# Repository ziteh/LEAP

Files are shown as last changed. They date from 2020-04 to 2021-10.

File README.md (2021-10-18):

:warning: This repo is no longer updated, I will continue to develop LEAP in [ziteh/LEAP-upper-limb](https://github.com/ziteh/LEAP-upper-limb).

---  

"**Lightweight Exoskeleton with Assistive Power (LEAP**)" is my independent study.

「**輔助性動力輕型外骨骼 (LEAP, 飛躍)**」是我的獨立研究。

# 影片展示

第二次步行測試 (https://www.youtube.com/watch?v=bzW2kFukcrA)

# 說明

## MCU

我使用的微控制器型號為 STM32F103RB，是基於 ARM Cortex M3 的 32 位元微控制器。

本專案使用的 IDE 爲[ Atollic TrueSTUDIO](https://atollic.com/truestudio/)，這是 ST 官方維護、由開源的[ Eclipse ](https://www.eclipse.org/downloads/)發展而來的 IDE。

目前本專案可正常運作的專案在[ LEAP/stm32/LAEPK_STM32_Cpp ](https://github.com/ziteh/LEAP/tree/master/stm32/LAEPK_STM32_Cpp)，可以使用 TrueSTUDIO 直接開啓專案。

## 電腦端程式

電腦端程式可以查看外骨骼的相關數值與狀態，也可以控制其動作等。

# 相關檔案

* STM32 微控制器程式： [LEAP/stm32/](https://github.com/ziteh/LEAP/tree/master/stm32/)
* 電腦端程式：[LEAP/PC_control_panel/](https://github.com/ziteh/LEAP/tree/master/PC_control_panel)
* 手機端程式：[LEAP-android-control-panel](https://github.com/ziteh/LEAP-android-control-panel)
* 3D 模型：[LEAP/3D_models/](https://github.com/ziteh/LEAP/tree/master/3D_models)
* PCB 電路：[LEAP/pcb/](https://github.com/ziteh/LEAP/tree/master/pcb)

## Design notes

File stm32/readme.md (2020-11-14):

# L.E.A.P stm32

這是 L.E.A.P 的 STM32 微控制器程式部分，使用 C/C++ 編寫，IDE 爲 TrueSTUDIO。

當前版本在[LAEPK_STM32_Cpp](LAEPK_STM32_Cpp)

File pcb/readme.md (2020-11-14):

# L.E.A.P pcb

這是 L.E.A.P 的 PCB 電路部分，使用 KiCad。

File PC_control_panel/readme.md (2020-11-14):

# L.E.A.P PC_control_panel

這是 L.E.A.P 的電腦端程式部分，使用 Visual Studio C# 編寫而成。

當前版本在[LEAP-ControlPanel](LEAP-ControlPanel)

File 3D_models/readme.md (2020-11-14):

# L.E.A.P 3D_models

這是 L.E.A.P 的 3D 模型部分。

當前版本在[Solidworks](Solidworks)

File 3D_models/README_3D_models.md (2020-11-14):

# L.E.A.P 3D_models

這是 L.E.A.P 的 3D 模型部分。

當前版本在[Solidworks](/Solidworks)

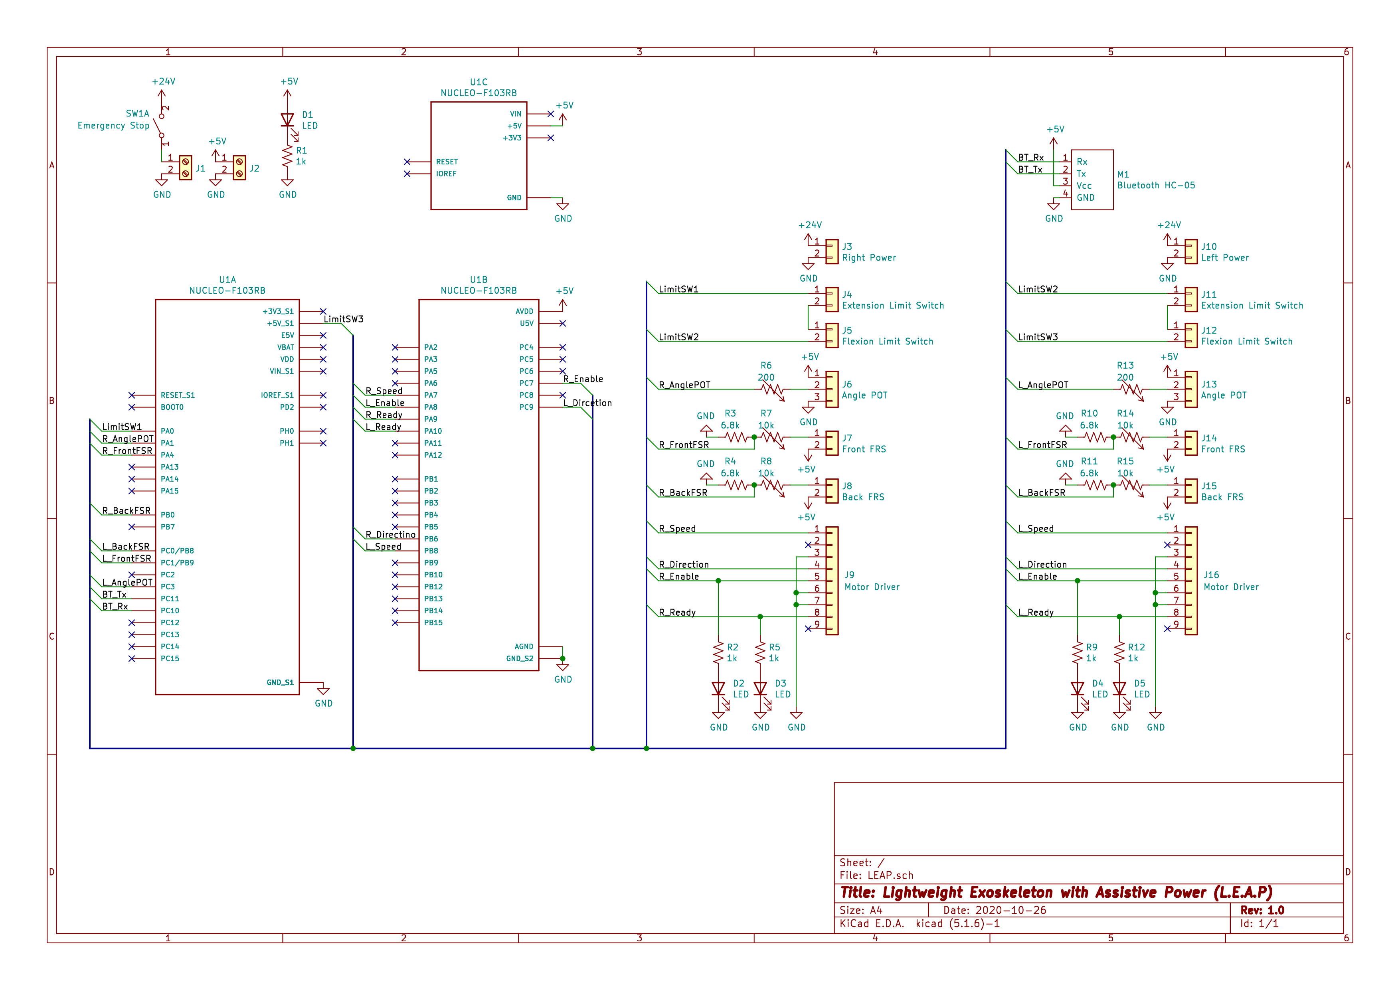
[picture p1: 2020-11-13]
pcb/LEAPsch-01.png

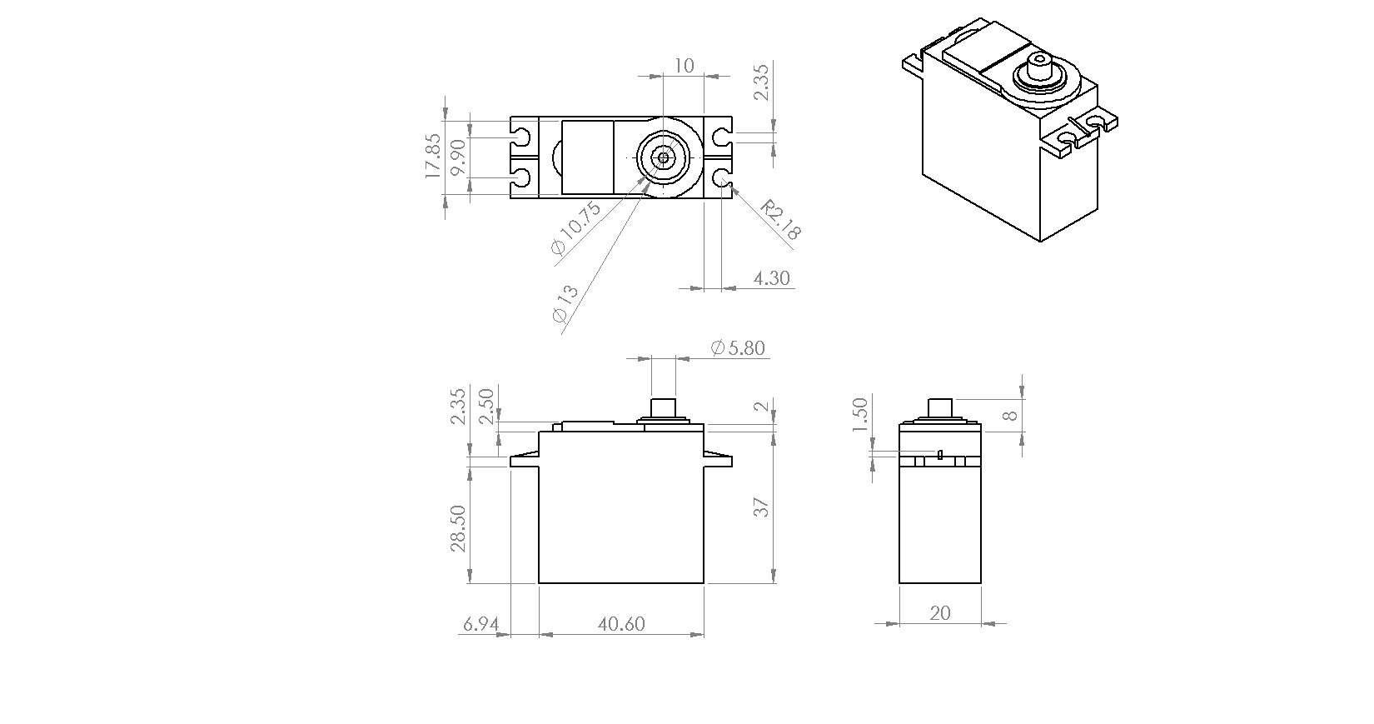
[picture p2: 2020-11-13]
3D_models/Solidworks/縮小測試用模型v2/MG996R[01-v1.PNG

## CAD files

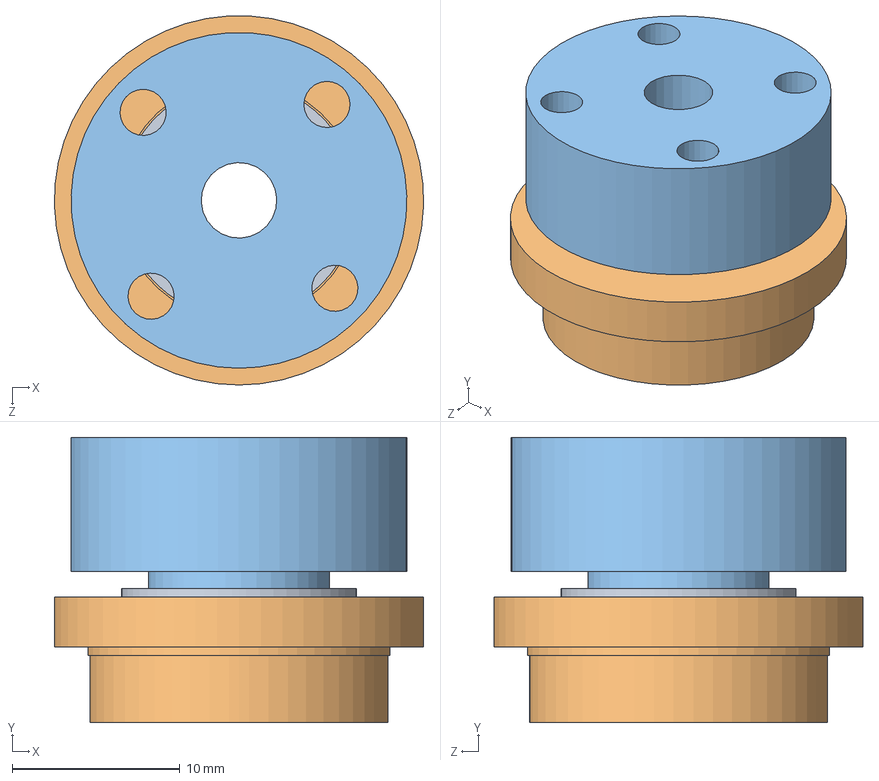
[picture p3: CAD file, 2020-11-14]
3D_models/Solidworks/下肢/組合/HD軸向固定組合[01_v2.0].SLDASM
22.0 x 17.0 x 22.0 mm
軸承_HD軸向固定(01-v1.0)
HD軸向軸承固定塊(01_v1.0)
HD軸向軸承固定塊(02_v2.0)

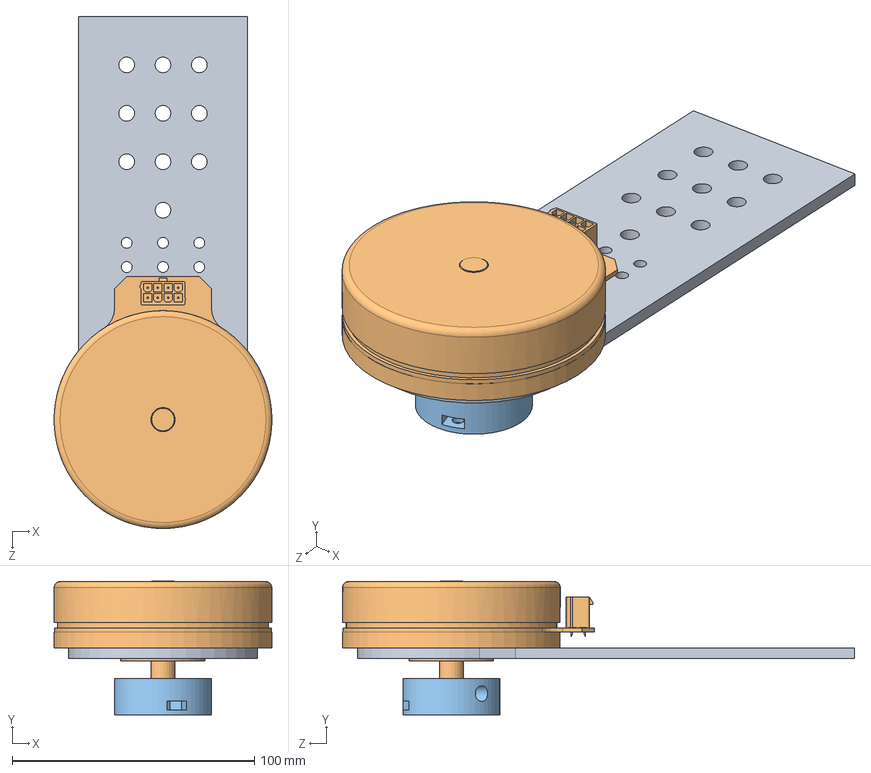
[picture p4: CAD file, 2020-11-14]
3D_models/Solidworks/下肢/組合/EC90flat固定片塊組合[01_v1.0].SLDASM
90.0 x 55.3 x 211.5 mm
EC90flot固定片(01_v3.1)
EC90fl-160W-586655
EC90flot軸心固定塊(01_v3.1)

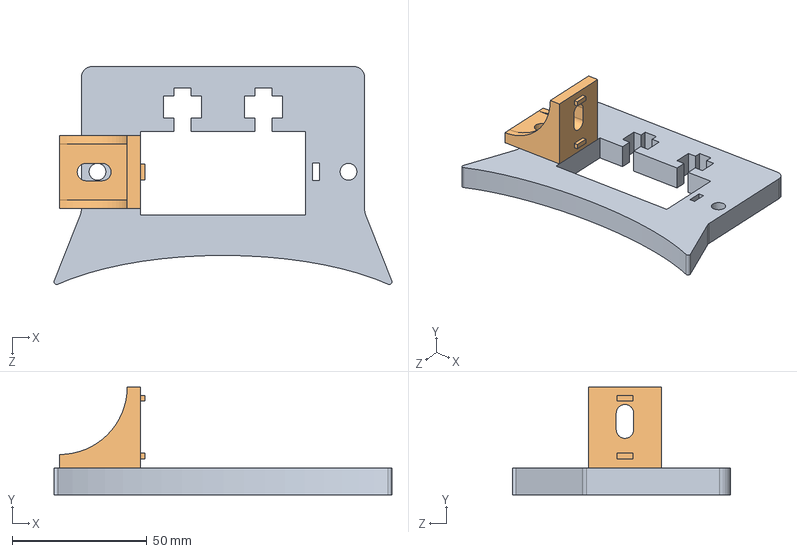
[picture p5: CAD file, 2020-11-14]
3D_models/Solidworks/下肢/組合/大腿固定片組合[01_v1.0].SLDASM
125.2 x 40.0 x 80.8 mm
大腿固定片[01_v1.0]
3030鋁擠型三角件M6[01-v1.0]

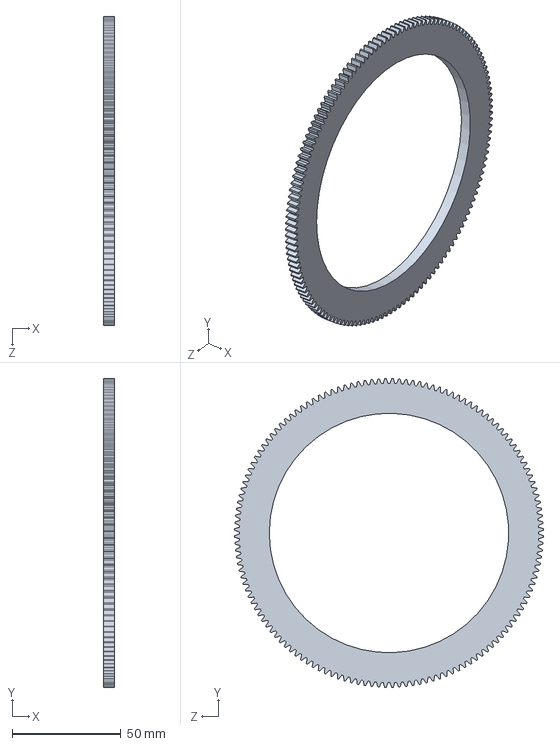
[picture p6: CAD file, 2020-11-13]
3D_models/Solidworks/下肢/Others/編碼器用大齒輪[01_v1.0].SLDASM
5.00 x 142.0 x 142.0 mm

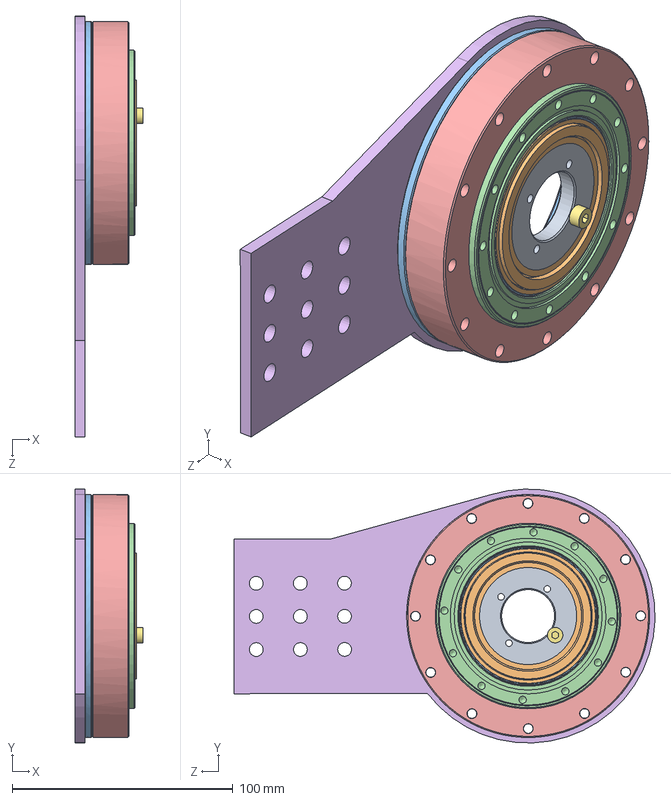
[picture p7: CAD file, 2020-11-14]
3D_models/Solidworks/下肢/組合/SHD-25-2SH固定片組合[01_v1.0].SLDASM
30.9 x 114.9 x 190.6 mm
SHD-25-2SH-WG
25 WG BEARING DS
SHD-25-2SH-FS
SHD-25-2SH-CS
SHD-25-2SH-FS2
SHD-2SH_彈性齒杯固定片(01_v4.2)

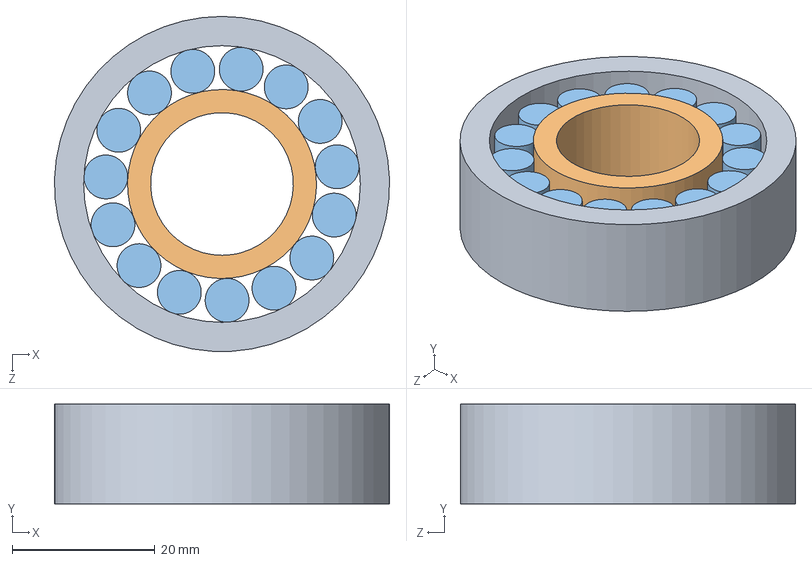
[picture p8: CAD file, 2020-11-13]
3D_models/Solidworks/下肢/機械/軸承(SKF單列圓柱滾子20)_組合-01_v1.0.SLDASM
47.0 x 14.0 x 47.0 mm
軸承(SKF單列圓柱滾子20)_外圈-01_v1.0
軸承(SKF單列圓柱滾子20)_内圈-01_v1.0
軸承(SKF單列圓柱滾子20)_滾子-01_v1.0

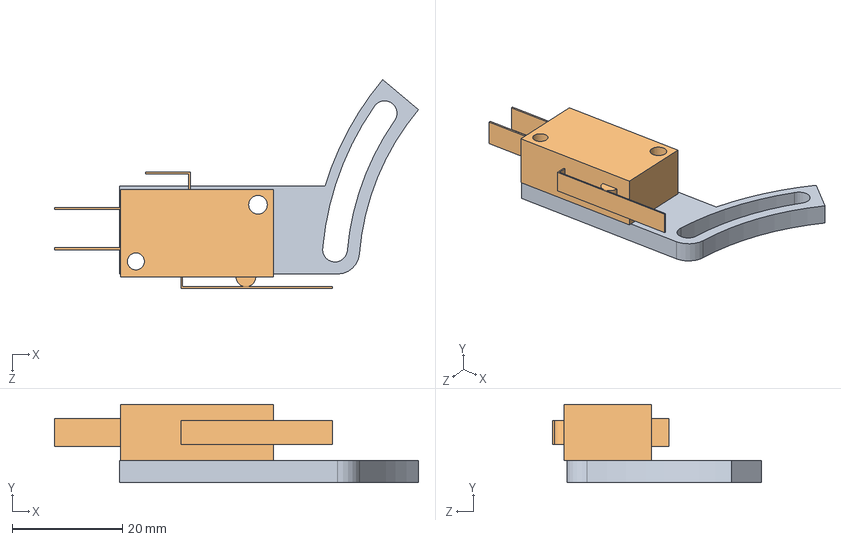
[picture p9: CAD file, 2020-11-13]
3D_models/Solidworks/下肢/組合/微動開關-固定片組合[01_v1.0].SLDASM
66.2 x 14.2 x 38.0 mm
微動開關固定片[01_v1.0]
微動開關_TMV101-C[01-v1.0]

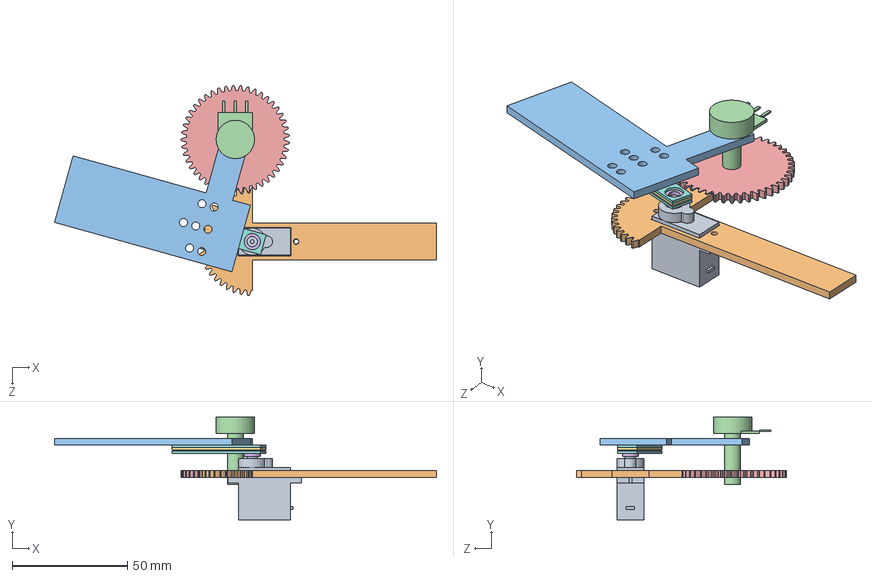
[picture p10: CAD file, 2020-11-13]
3D_models/Solidworks/縮小測試用模型/pwEXO縮小測試模型完整組合[01-v1.0].SLDASM
165.9 x 44.6 x 91.3 mm
伺服馬達SG90[01-v1.0]
伺服馬達SG90固定板-小腿[01-v3.0]
伺服馬達SG90固定板-大腿[01-v1.0]
可變電阻[01-v1.0]
可變電阻齒輪[01-v2.0]
伺服馬達SG90用轉軸片[01-v1.0]
伺服馬達SG90用轉軸片壓克力套[01-v1.0]
伺服馬達SG90用轉軸片壓克力套[02-v1.0] x 2

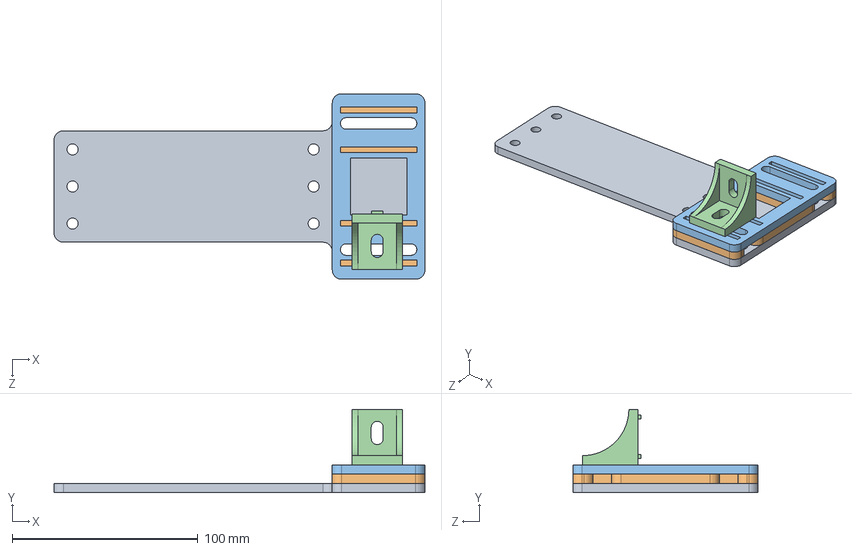
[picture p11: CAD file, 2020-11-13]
3D_models/Solidworks/下肢/組合/腳底板組合[01_v1.0].SLDASM
200.0 x 45.0 x 100.0 mm
腳底板固定片[01_v1.0]
腳底板螺帽固定片[01_v1.0]
腳底板螺帽固定片[02_v1.0]
3030鋁擠型三角件M6[01-v1.0]

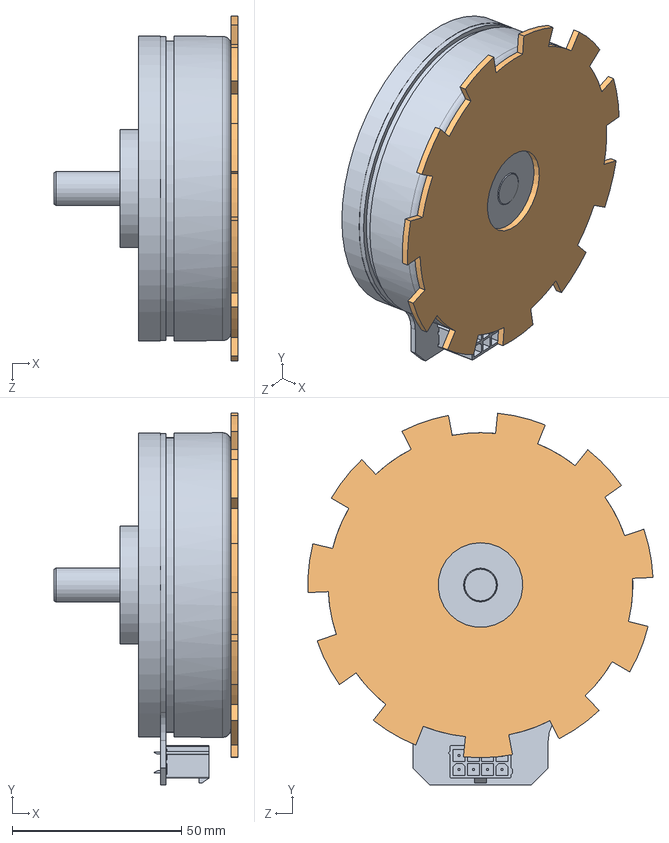
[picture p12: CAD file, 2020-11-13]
3D_models/Solidworks/下肢/組合/測試光遮斷輪用模型[01_v1.0].SLDASM
54.3 x 109.8 x 101.9 mm
EC90fl-160W-586655
光遮斷輪[01-v1.0]

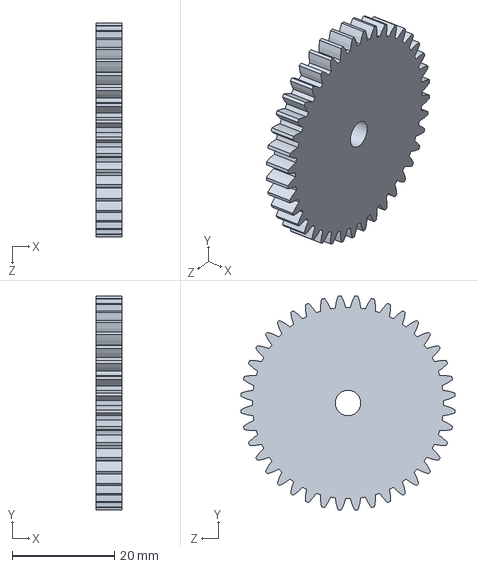
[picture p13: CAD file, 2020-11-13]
3D_models/Solidworks/縮小測試用模型v2/齒輪[01-v1.0].SLDASM
5.00 x 41.9 x 41.9 mm

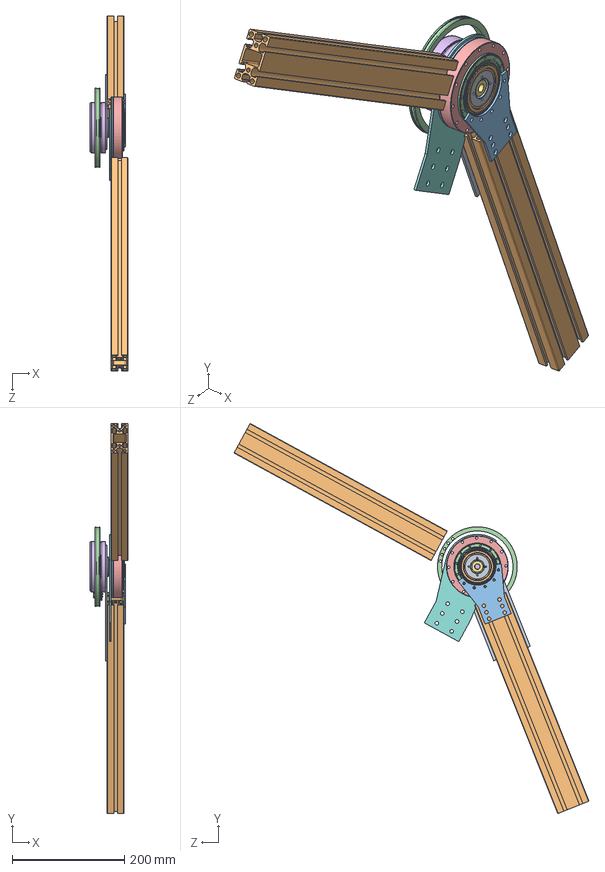
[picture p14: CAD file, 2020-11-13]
3D_models/Solidworks/下肢/組合/腿部組合-L[01_v2.1(時規皮帶)].SLDASM
67.8 x 694.9 x 632.2 mm
SHD-25-2SH-WG
25 WG BEARING DS
SHD-25-2SH-FS
SHD-25-2SH-CS
SHD-25-2SH-FS2
EC90fl-160W-586655
EC90flot軸心固定塊(01_v2.0)
SHD-2SH_彈性齒杯固定片(01_v4.0)
EC90flot固定片(01_v3.0)
3060鋁擠型(400)-01_v1.0 x 2
SHD-2SH_剛性齒輪固定片(01_v2.0)
編碼器大同步輪[01-v1.0]

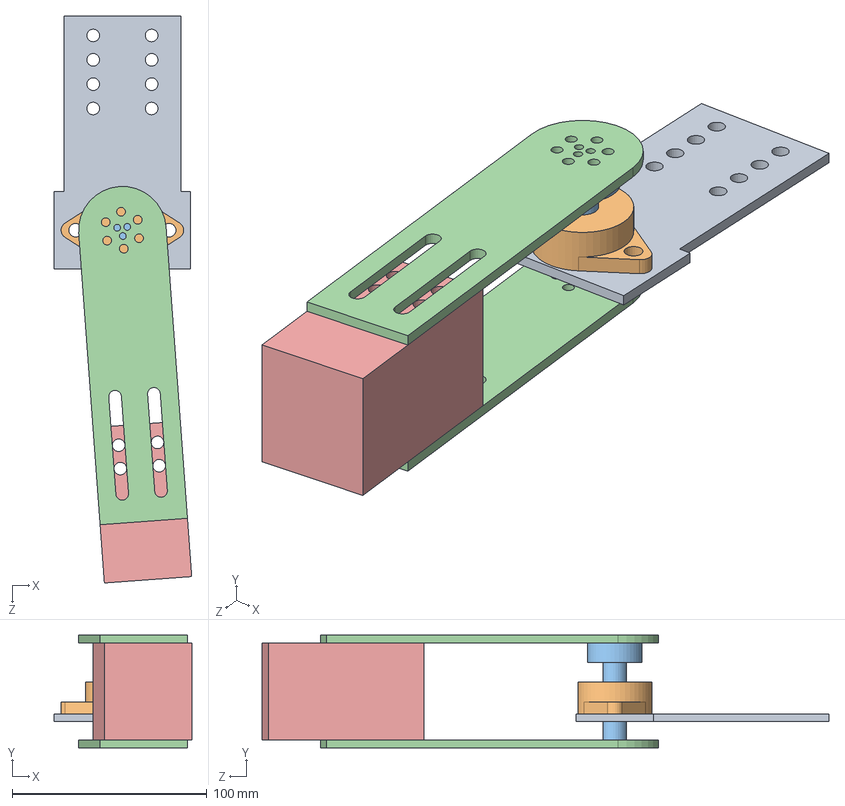
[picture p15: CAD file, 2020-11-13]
3D_models/Solidworks/下肢/組合/軸承固定座-KFL12組合[01-v1.0].SLDASM
70.6 x 58.0 x 291.2 mm
軸承固定座-KFL12固定片[01-v1.0]
軸承固定座-KFL12[01-v1.0]
腳踝軸承軸心固定塊[01_v1.0]
腳踝軸承軸心固定片[01_v1.0] x 2
腳底板固定塊[01_v1.0]

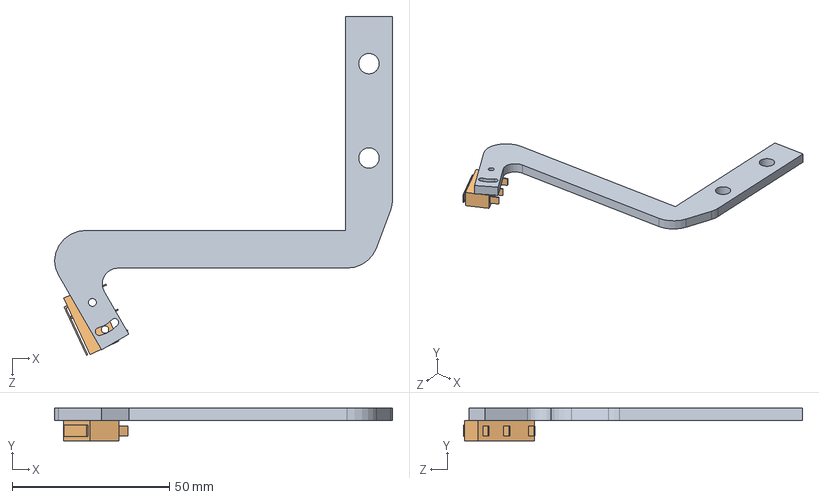
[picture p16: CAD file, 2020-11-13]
3D_models/Solidworks/下肢/組合/微動開關(SS-5GL)-固定片組合[02_v1.0(彎曲)].SLDASM
107.5 x 10.4 x 107.8 mm
微動開關(SS-5GL)固定片[02_v1.0]
微動開關_SS-5GL[01-v1.0]

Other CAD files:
3D_models/Solidworks/下肢/組合/多圈可變電阻定位齒輪組[01-v1.0].SLDASM
3D_models/Inventor/機械/HarmonicDrive/25 WG BEARING DS.ipt
3D_models/Inventor/機械/HarmonicDrive/SHD-25-2SH-CS.ipt
3D_models/Inventor/機械/HarmonicDrive/SHD-25-2SH-FS.ipt
3D_models/Inventor/機械/HarmonicDrive/SHD-25-2SH-FS2.ipt
3D_models/Inventor/機械/HarmonicDrive/SHD-25-2SH-WG.ipt
3D_models/Inventor/機械/HarmonicDrive/SHD-25-xxx-2SH.iam
3D_models/Inventor/鋁擠型/3060鋁擠型(Prototype)-01_v1.DXF
3D_models/Inventor/鋁擠型/3060鋁擠型-小腿[01_v1.0].ipt
3D_models/Inventor/電子電機/EC90fl-160W-586655.ipt
3D_models/Solidworks/下肢/Others/光遮斷輪[01-v1.0].SLDPRT
3D_models/Solidworks/下肢/Others/編碼器大同步輪[01-v1.0].SLDPRT
3D_models/Solidworks/下肢/Others/編碼器大齒輪[01-v1.0].SLDPRT
3D_models/Solidworks/下肢/Others/編碼器大齒輪[01-v2.0].SLDPRT
3D_models/Solidworks/下肢/Others/腳底板-01_v1.0.SLDPRT
3D_models/Solidworks/下肢/Others/腳踝部[01-v1.0].SLDPRT
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

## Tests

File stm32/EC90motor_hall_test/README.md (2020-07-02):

# LAEPK-stm32

這是我的大學畢業專題（Independent Study）：

動力膝關節輕簡補助型外骨骼（Lightweight Assistive Exoskeleton with the Powered Knee Joint，L.A.E.P.K.）

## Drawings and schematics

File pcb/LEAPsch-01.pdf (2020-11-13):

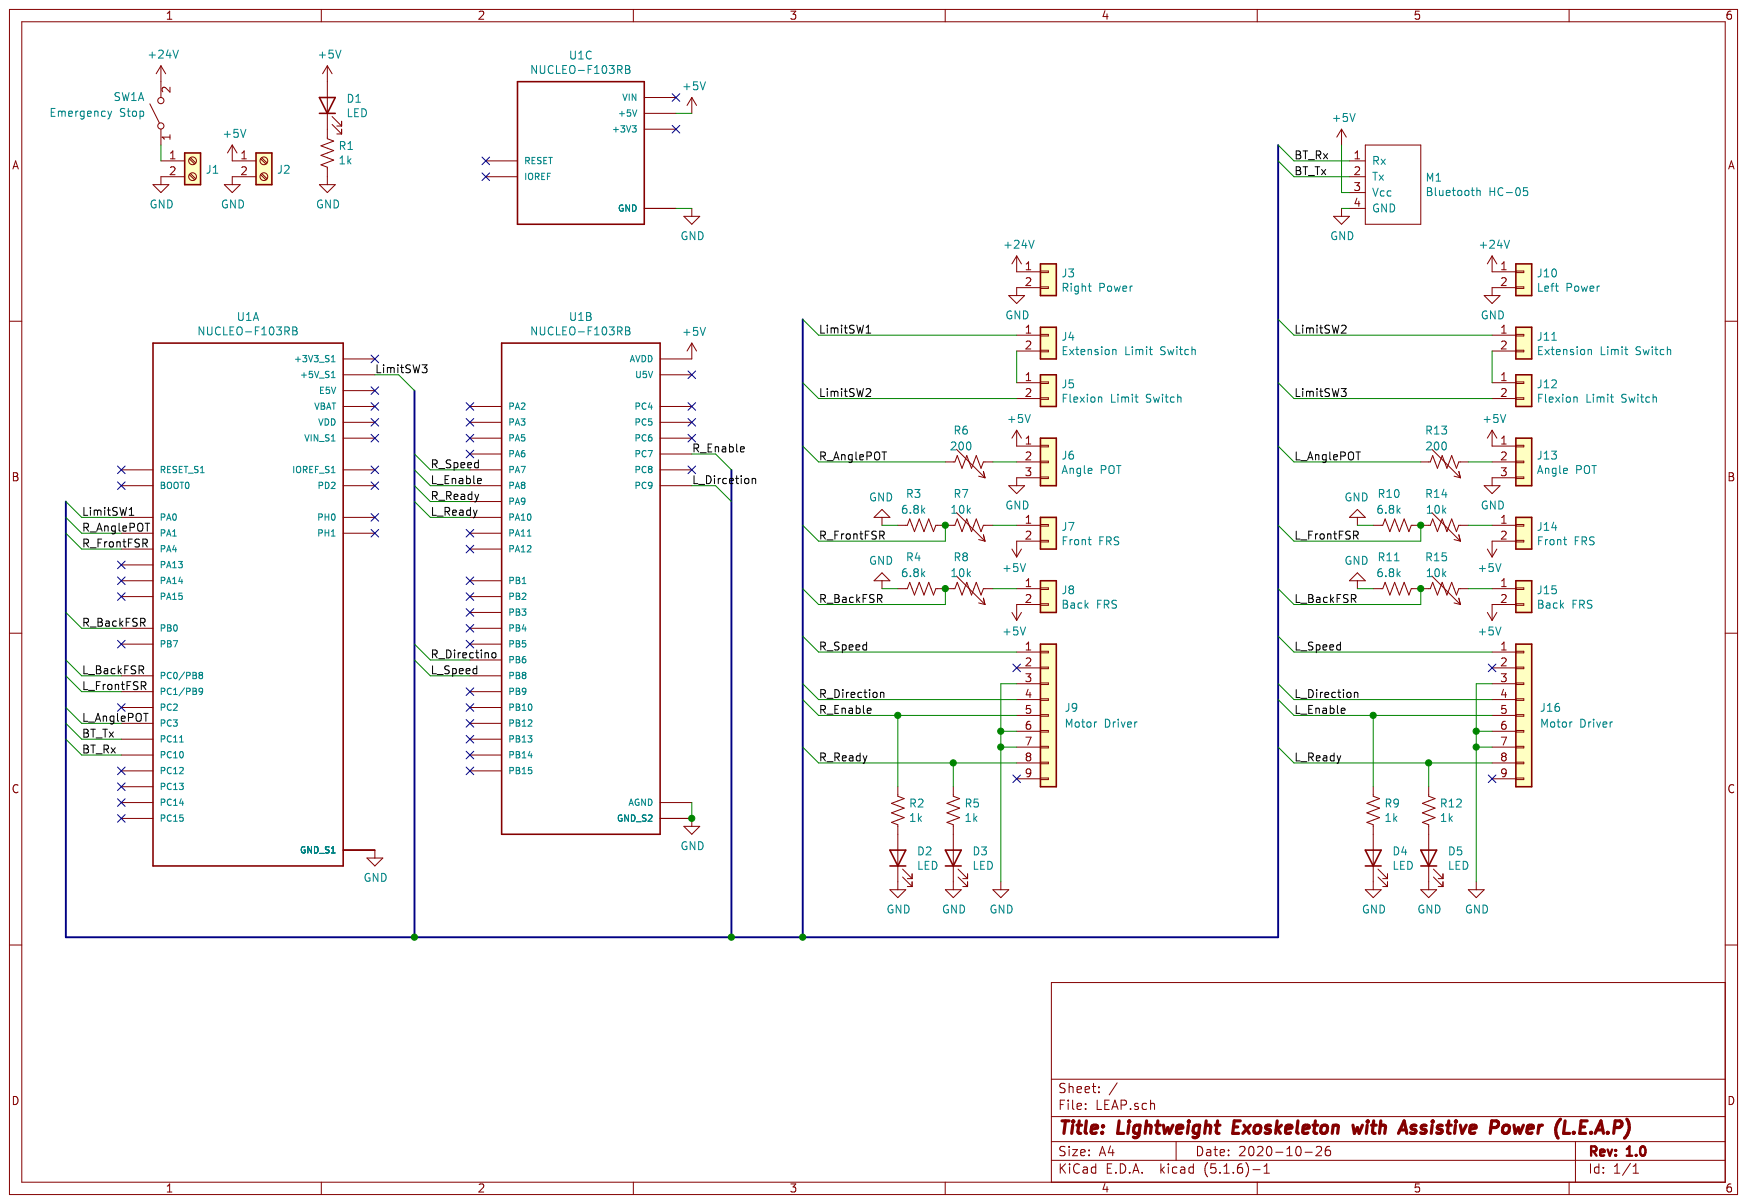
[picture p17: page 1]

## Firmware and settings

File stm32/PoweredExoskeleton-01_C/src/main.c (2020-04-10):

/**
 ******************************************************************************
 * @file   		main.c
 *	@author  	Huang, Tzu-Fu
 * 				National Formosa University
 * 				Department of Electronic Engineering
 * 				Intelligent Robot System Laboratory
 * @version 	V1.0.0
 * @date    	25-October-2019
 * @brief   	Main program body of Powered Exoskeleton
 ******************************************************************************
 * @attention
 *
 * None
 *
 ******************************************************************************
 */

/* Includes ------------------------------------------------------------------*/
#include <stdio.h>
#include "stm32f10x.h"
#include "main.h"
#include "GPIO_Functions.h"
#include "RCC_Functions.h"
#include "NVIC_Functions.h"
#include "USART_Functions.h"
#include "PWM_Functions.h"

/** @addtogroup Powered Exoskeleton
  * @{
  */ 

/* Private typedef -----------------------------------------------------------*/
RCC_ClocksTypeDef RCC_Clocks;

/* Private define ------------------------------------------------------------*/
#define Enable 	(1)
#define Disable (0)
#define CW		(0)
#define CCW		(1)

/* Private macro -------------------------------------------------------------*/
/* Private variables ---------------------------------------------------------*/
static __IO uint32_t TimingDelay;
uint8_t BlinkSpeed = 0;

/* Motor */
// Row: Motor number; Column: The pin of Enable,Direction,Ready
uint8_t MotorPin[2][3] =
{	// | Enable | Direction | Ready |
	{PinMotor0_Enbale, PinMotor0_Direction, PinMotor0_Ready},	// Motor0
	{PinMotor1_Enbale, PinMotor1_Direction, PinMotor1_Ready}	// Motor1
};

// The PWM timer of Motor0, Motor1
uint32_t MotorTimer[2] = {TIM3, TIM3};

//uint8_t Motor0_Speed_Char[] = "0";
//uint8_t Motor0_Speed_Value = 0;

/* Private function prototypes -----------------------------------------------*/
/* Private functions ---------------------------------------------------------*/

/**
 * @brief   Main program
 * @param  None
 * @retval None
 */
int main(void)
{
	/*!< At this stage the microcontroller clock setting is already configured,
	 this is done through SystemInit() function which is called from startup
	 file (startup_stm32f10x_md.s) before to branch to application main.
	 To reconfigure the default setting of SystemInit() function, refer to
	 system_stm32f10x.c file
	 */

	/* SysTick end of count event each 1ms */
	RCC_GetClocksFreq(&RCC_Clocks);
	SysTick_Config(RCC_Clocks.HCLK_Frequency / 1000);

	/* Initialization */
	// Functions & Setups
	RCC_Initialization();
	GPIO_Initialization();
	USART_Initialization();
	PWM_Initialization();
	NVIC_Initialization();

	// Reset all motor
	TIM_SetCompare1(TIM3, 0);		// Immediately set motor0 speed=0%
	MotorCtrl(0, Disable, CCW, 0);	// Motor0: Disable, CCW, Speed:0%
	MotorCtrl(1, Disable, CW, 0);	// Motor1: Disable,  CW, Speed:0%

	// Turn off LD2(User-LED)
	Pin_Clr(LD2);

	USART_Send(USART2, "[System]Start.\n");

	/* Infinite loop */
	while(1)
	{
		SendStatus();
		Delay(250);
	}
}

/**
* @brief  	Send status.
* @param	None
* @retval 	None
*/
void SendStatus(void)
{
//	uint8_t TxData;

	// Binary:010nnrXX
//	TxData = ((0x40 | (Motor << 3)) | (Pin_Read(MotorPin[Motor][2]) << 2));
//	USART_Send(USART2, TxData);

	// Motor0
	USART_Send(USART2, "[Status]Motor0 ");
	if(Pin_ReadInput(PinMotor0_Ready) == 1)	// Motor_Ready pin=High
		USART_Send(USART2, "Ready ; ");
	else									// Motor_Ready pin=Low
		USART_Send(USART2, "FAULT ; ");

	if(Pin_ReadOutput(PinMotor0_Enbale) == 1)
		USART_Send(USART2, " Enable ; ");
	else
		USART_Send(USART2, "Disable ; ");

	if(Pin_ReadOutput(PinMotor0_Direction) == 1)
		USART_Send(USART2, "CCW ; ");
	else
		USART_Send(USART2, " CW ; ");

	USART_Send(USART2, "S: ");
	USART_Send(USART2, Number_TO_String(PerMill_TO_Percentage(TIM3->CCR1)));
	USART_Send(USART2, "%\n");

	// Motor1
	USART_Send(USART2, "[Status]Motor1 ");
	if(Pin_ReadInput(PinMotor1_Ready) == 1)	// Motor_Ready pin=High
		USART_Send(USART2, "Ready ; ");
	else									// Motor_Ready pin=Low
		USART_Send(USART2, "FAULT ; ");

	if(Pin_ReadOutput(PinMotor1_Enbale) == 1)
		USART_Send(USART2, " Enable ; ");
	else
		USART_Send(USART2, "Disable ; ");

	if(Pin_ReadOutput(PinMotor1_Direction) == 1)
		USART_Send(USART2, "CCW\n");
	else
		USART_Send(USART2, " CW\n");

	USART_Send(USART2, "----------\n");
}

/**
* @brief  	Control the motor.
* @param	Motor: the number of motor. This parameter should be: 0~1.
* @param	Status: the status of motor.
* 			This parameter should be 0~3.
* 			0: Disable; 1: Enable; 2: Toggle; 3: Keep.
* @param	Direction: the direction of motor.
* 			This parameter should be 0~3.
* 			0: CW; 1: CCW; 2: Toggle; 3: Keep.
* @param	Speed: the speed of motor in %.
* 			This parameter should be: 0~100, 127.
* 			0~100: 0%~100%; 127: Keep.
* @retval 	None
*/
void MotorCtrl(uint8_t Motor, uint8_t Status, uint8_t Direction, uint16_t Speed)
{
//	u16 DutyCycleValue;

	// Status
	if(Status <= 1)								// Disable(0) & Enable(1)
		Pin_Write((MotorPin[Motor][0]), Status);
	else if(Status == 2)						// Toggle(2)
		Pin_Toggle(MotorPin[Motor][0]);
	else /* Null */;							// Keep(3)

	// Direction
	if(Direction <= 1)							// CW(0) & CCW(1)
		Pin_Write((MotorPin[Motor][1]), Direction);
	else if(Direction == 2)						// Toggle(2)
		Pin_Toggle(MotorPin[Motor][1]);
	else /* Null */;							// Keep(3)

	// Speed
	if(Speed == 0)	// Turn OFF the motor
	{
		Pin_Write((MotorPin[Motor][0]), Disable);
//		TIM_SetCompare1((MotorTimer[Motor]), 0);
		MotorAccelerationCtrl(Motor, 0);
//		Motor0_Speed_Value = Speed;
	}
	else if(Speed == 100)
	{
//		TIM_SetCompare1((MotorTimer[Motor]), 999);	// Set PWM duty cycle=100%
		MotorAccelerationCtrl(Motor, 999);		// Set PWM duty cycle=100%
//		Motor0_Speed_Value = Speed;
	}
	else if((Speed > 0) && (Speed < 100))
	{
//		TIM_SetCompare1((MotorTimer[Motor]), ((Speed-1)*10)); // Set duty cycle
		MotorAccelerationCtrl(Motor, ((Speed*10)-1));	// Set duty cycle
//		Motor0_Speed_Value = Speed;
	}
	else if(Speed == 127)	// Keep the speed of motor
	{
		/* Null */;
	}
	else /* Null */;
}

/**
 * @brief	Motor acceleration control
 * @param 	Motor: The motor want to control.
 * @param 	TargetSpeed: The Target speed.
 */
void MotorAccelerationCtrl(uint8_t Motor, uint16_t TargetSpeed)
{
	while(TargetSpeed != (TIM3->CCR1))
	{
		uint16_t NowSpeed = (TIM3->CCR1);	// Read PMW Duty-Cycle% Value
//		int32_t SpeedDif = TargetSpeed - NowSpeed;

		// Set duty cycle
		if((TargetSpeed - NowSpeed) > 0)
		{
			TIM_SetCompare1((MotorTimer[Motor]), (NowSpeed+1));
		}
		else if((TargetSpeed - NowSpeed) < 0)
		{
			TIM_SetCompare1((MotorTimer[Motor]), (NowSpeed-1));
		}

		Delay_normal(0xFCF);
	}
}

/**
 * @brief	Convert number into string
 * @param 	Number: The number want to convert.
 * @return	The converted string.
 */
char* Number_TO_String(uint16_t Number)
{
	static char string[3];
	sprintf(string, "%d", Number);
	return string;
}

/**
 * @brief	Convert 0~999 into 0~100
 * @param 	PerMill: The PerMill number want to convert. 0~999.
 * @return	The converted percentage.
 */
u8 PerMill_TO_Percentage(u16 PerMill)
{
	u8 Percentage;

	if(PerMill == 0)
		Percentage = 0;
	else if(PerMill == 999)
		Percentage = 100;
	else if((PerMill > 1) && (PerMill < 999))
		Percentage = ((PerMill+1)/10);
	else /* Null */;

	return Percentage;
}

/**
 * @brief  Inserts a delay time(no-interrupt).
 * @param  nTime: specifies the delay time length.
 * @retval None
 */
void Delay_normal(__IO u32 nTime)
{
	for(; nTime != 0; nTime--);
}

/**
 * @brief  Inserts a delay time.
 * @param  nTime: specifies the delay time length, in 1 ms.
 * @retval None
 */
void Delay(__IO uint32_t nTime)
{
	TimingDelay = nTime;

	while (TimingDelay != 0)
		/* Null */;
}

/**
 * @brief  Decrements the TimingDelay variable.
 * @param  None
 * @retval None
 */
void TimingDelay_Decrement(void)
{
	if (TimingDelay != 0x00)
	{
		TimingDelay--;
	}
}

#ifdef  USE_FULL_ASSERT

/**
 * @brief  Reports the name of the source file and the source line number
 *         where the assert_param error has occurred.
 * @param  file: pointer to the source file name
 * @param  line: assert_param error line source number
 * @retval None
 */
void assert_failed(uint8_t* file, uint32_t line)
{
	/* User can add his own implementation to report the file name and line number,
	 ex: printf("Wrong parameters value: file %s on line %d\r\n", file, line) */

	/* Infinite loop */
	while (1)
	{
	}
}
#endif

/**
* @}
*/


/************************ (C) COPYRIGHT STMicroelectronics *****END OF FILE****/

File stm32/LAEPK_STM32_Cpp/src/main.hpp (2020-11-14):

/**
 ******************************************************************************
 * @file    main.hpp
 * @author  ZiTe (honmonoh@gmail.com)
 * @version V1.0
 * @date    14-November-2020
 * @brief   Header for main.cpp module
 ******************************************************************************
 * @attention
 *
 * None
 *
 ******************************************************************************
 */

/* Define to prevent recursive inclusion */
#ifndef __MAIN_H
#define __MAIN_H

#include <string>
#include <sstream>
#include <cmath>
#include "GPIO_Functions.hpp"
#include "PWM_Functions.hpp"
#include "USART_Functions.hpp"
#include "ADC_Functions.hpp"
#include "EC90fl_Motor_Functions.hpp"
#include "joint.hpp"
#include "unit_test.hpp"

extern "C"
{
#include <stdio.h>
#include "stm32f10x.h"
}

#define LimitSwitch_PortPin ((GPIO_PortPinTypeDef)PA0)

/* Right leg define */
#define RightJoint_PortPin_SpeedPWM ((GPIO_PortPinTypeDef)PA7)
#define RightJoint_Timer_SpeedPWM (TIM3)
#define RightJoint_Channel_SpeedPWM (CH2)

#define RightJoint_PortPin_FunctionState ((GPIO_PortPinTypeDef)PC7)
#define RightJoint_PortPin_Direction ((GPIO_PortPinTypeDef)PB6)
#define RightJoint_PortPin_ReadyState ((GPIO_PortPinTypeDef)PA9)

#define RightJoint_PortPin_AnglePOT ((GPIO_PortPinTypeDef)PA1)
#define RightJoint_ADCx_AnglePOT (ADC1)
#define RightJoint_ADC_Channel_AnglePOT (ADC_Channel_1)

#define RightJoint_PortPin_FrontFSR ((GPIO_PortPinTypeDef)PA4)
#define RightJoint_ADCx_FrontFSR (ADC1)
#define RightJoint_ADC_Channel_FrontFSR (ADC_Channel_4)

#define RightJoint_PortPin_BackFSR ((GPIO_PortPinTypeDef)PB0)
#define RightJoint_ADCx_BackFSR (ADC1)
#define RightJoint_ADC_Channel_BackFSR (ADC_Channel_8)

#define RightJoint_DefaultValue_POTFullExtension ((uint16_t)1400)
#define RightJoint_DefaultValue_POTFullFlexion ((uint16_t)2450)

#define RightJoint_DefaultValue_FSRStartExtension ((uint16_t)2000)
#define RightJoint_DefaultValue_FSRStartFlexion ((uint16_t)2500)

#define RightJoint_DefaultValue_FSRStopExtension ((uint16_t)RightJoint_DefaultValue_FSRStartFlexion - 200)
#define RightJoint_DefaultValue_FSRStopFlexion ((uint16_t)RightJoint_DefaultValue_FSRStartExtension - 200)

#define RightJoint_Reverse ((bool) false)

/* Left leg define */
#define LeftJoint_PortPin_SpeedPWM ((GPIO_PortPinTypeDef)PB8)
#define LeftJoint_Timer_SpeedPWM (TIM4)
#define LeftJoint_Channel_SpeedPWM (CH3)

#define LeftJoint_PortPin_FunctionState ((GPIO_PortPinTypeDef)PA8)
#define LeftJoint_PortPin_Direction ((GPIO_PortPinTypeDef)PC9)
#define LeftJoint_PortPin_ReadyState ((GPIO_PortPinTypeDef)PA9)

#define LeftJoint_PortPin_AnglePOT ((GPIO_PortPinTypeDef)PC3)
#define LeftJoint_ADCx_AnglePOT (ADC1)
#define LeftJoint_ADC_Channel_AnglePOT (ADC_Channel_13)

#define LeftJoint_PortPin_FrontFSR ((GPIO_PortPinTypeDef)PC1)
#define LeftJoint_ADCx_FrontFSR (ADC1)
#define LeftJoint_ADC_Channel_FrontFSR (ADC_Channel_11)

#define LeftJoint_PortPin_BackFSR ((GPIO_PortPinTypeDef)PC0)
#define LeftJoint_ADCx_BackFSR (ADC1)
#define LeftJoint_ADC_Channel_BackFSR (ADC_Channel_10)

#define LeftJoint_DefaultValue_POTFullExtension ((uint16_t)1400)
#define LeftJoint_DefaultValue_POTFullFlexion ((uint16_t)435)

#define LeftJoint_DefaultValue_FSRStartExtension ((uint16_t)1400)
#define LeftJoint_DefaultValue_FSRStartFlexion ((uint16_t)1600)

#define LeftJoint_DefaultValue_FSRStopExtension ((uint16_t)LeftJoint_DefaultValue_FSRStartFlexion - 250)
#define LeftJoint_DefaultValue_FSRStopFlexion ((uint16_t)LeftJoint_DefaultValue_FSRStartExtension - 250)

#define LeftJoint_Reverse ((bool) true)

#define LeftJoint_PortPin_VirtualHall1 ((GPIO_PortPinTypeDef)PB8)
#define LeftJoint_PortPin_VirtualHall2 ((GPIO_PortPinTypeDef)PB9)
#define LeftJoint_PortPin_VirtualHall3 ((GPIO_PortPinTypeDef)PA6)

/* Limit switch */
#define NVIC_PreemptionPriority_EXTI0 (0)
#define NVIC_SubPriority_EXTI0 (0)

/* User button */
#define NVIC_PreemptionPriority_EXTI15_10 (3)
#define NVIC_SubPriority_EXTI15_10 (3)

/* Main timer */
#define NVIC_PreemptionPriority_TIM2 (2)
#define NVIC_SubPriority_TIM2 (0)

/* Virtual hall sensor timer */
#define NVIC_PreemptionPriority_TIM4 (2)
#define NVIC_SubPriority_TIM4 (1)

/* USB */
#define NVIC_PreemptionPriority_USART2 (1)
#define NVIC_SubPriority_USART2 (0)

/* Bluetooth */
#define NVIC_PreemptionPriority_USART3 (1)
#define NVIC_SubPriority_USART3 (1)

typedef enum
{
  Right,
  Left
} JointTypeDef;

void MotionHandler(void);
void MotionEmergencyStop(void);
void UpdateInfo(void);

/**
 * @brief Initializing RCC.
 */
void RCC_Initialization(void);

/**
 * @brief Initializing limit switch.
 * @remark RCC_APB2: GPIOA
 */
void LimitSwitch_Initialization(void);

/**
 * @brief Initializing USART.
 * @remark RCC_APB1: USART2
 *         RCC_APB2: GPIOA
 */
void USART_Initialization(void);

/**
 * @brief Initializing timer.
 * @remark RCC_APB1: TIM2
 */
void Timer_Initialization(void);
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

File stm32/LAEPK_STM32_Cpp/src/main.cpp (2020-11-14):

/**
 ******************************************************************************
 * @file    main.cpp
 * @author  ZiTe (honmonoh@gmail.com)
 * @version V1.0
 * @date    14-November-2020
 * @brief   Main program body of L.E.A.P
 ******************************************************************************
 * @attention
 *
 * None
 *
 ******************************************************************************
 * @remark
 *
 * English is not my native language, please excuse typing errors.
 *
 ******************************************************************************
 */

#include "main.hpp"

/* Uncomment/Comment the line below to enable/disable speciflc features */
#define ENABLE_RIGHT_LEG
#define ENABLE_LEFT_LEG
//#define ENABLE_UNIT_TEST /* Uncomment it to run unit test program, comment it to run main program. */
#define ENABLE_AUTO_SEND_INFO

static __IO uint32_t TimingDelay;
RCC_ClocksTypeDef RCC_Clocks;

Joint *NowJoint = NULL;
Joint RightJoint;
Joint LeftJoint;

int main(void)
{
#ifndef ENABLE_UNIT_TEST
  /* Region of Main Code */

  /* Configures the NVIC priority grouping */
  NVIC_PriorityGroupConfig(NVIC_PriorityGroup_2);

  /* Initialization */
  RCC_Initialization();
#ifdef ENABLE_RIGHT_LEG
  Joint_Initialization(&RightJoint, Right);
#endif
#ifdef ENABLE_LEFT_LEG
  Joint_Initialization(&LeftJoint, Left);
#endif
  USART_Initialization();
  Board_Initialization();
  LimitSwitch_Initialization();
  Timer_Initialization();

  GPIO limitSwitch(LimitSwitch_PortPin);
  if (limitSwitch.getInputValue() == HIGH)
  {
    TIM_Cmd(TIM2, ENABLE); // Enable timer2(main program).
    USART_Send(USART2, "[L.A.E.P.K. READY]\r\n");
  }
  else
  {
    TIM_Cmd(TIM2, DISABLE); // Disable timer2(main program).
    MotionEmergencyStop();
    USART_Send(USART2, "[Check Limit-Switch]\r\n");
  }

  /* SysTick end of count event each 1ms */
  SysTick_Config(RCC_Clocks.HCLK_Frequency / 1000);
  USART_Send(USART2, "SysFre: ");
  USART_Send(USART2, Convert::ToString(RCC_Clocks.SYSCLK_Frequency));
  USART_Send(USART2, "\r\n");

  while (1)
  {
#ifdef ENABLE_AUTO_SEND_INFO
    // FIXME Can't send data.
    // StateTransporter();
    // Delay_ms(10);
#endif
  }
#else  /* ENABLE_UNIT_TEST */
  /* Region of Unit Test Code */
  RCC_GetClocksFreq(&RCC_Clocks);
  UnitTest::PWM_Output_1kHz_50DutyCycle();
#endif /* ENABLE_UNIT_TEST */
}

void MotionHandler(void)
{
#ifdef ENABLE_RIGHT_LEG
  NowJoint = &RightJoint;
  NowJoint->MotionHandler();
#endif

#ifdef ENABLE_LEFT_LEG
  NowJoint = &LeftJoint;
  NowJoint->MotionHandler();
#endif
}

void MotionEmergencyStop(void)
{
#ifdef ENABLE_RIGHT_LEG
  NowJoint = &RightJoint;
  NowJoint->MotionStop();
#endif

#ifdef ENABLE_LEFT_LEG
  NowJoint = &LeftJoint;
  NowJoint->MotionStop();
#endif

  USART_Send(USART2, "[EMER STOP]\n");
}

void UpdateInfo(void)
{
#ifdef ENABLE_RIGHT_LEG
  USART_Send(USART2, "[Right INFO]\n");
  NowJoint = &RightJoint;
  NowJoint->SendInfo();
#endif

#ifdef ENABLE_LEFT_LEG
  USART_Send(USART2, "[Left INFO]\n");
  NowJoint = &LeftJoint;
  NowJoint->SendInfo();
#endif
}

// FIXME Manual RCC init.
void RCC_Initialization(void)
{
  // RCC_DeInit();

  // RCC_HSICmd(ENABLE);
  // while (RCC_GetFlagStatus(RCC_FLAG_HSIRDY) == RESET)
  // {
  // }

  // RCC_HCLKConfig(RCC_SYSCLK_Div1);
  // RCC_PCLK1Config(RCC_HCLK_Div2);
  // RCC_PCLK2Config(RCC_HCLK_Div1);

  // FLASH_SetLatency(FLASH_Latency_2);
  // FLASH_PrefetchBufferCmd(FLASH_PrefetchBuffer_Enable);

  // RCC_PLLConfig(RCC_PLLSource_HSE_Div2, RCC_PLLMul_16);
  // RCC_PLLCmd(ENABLE);
  // while (RCC_GetFlagStatus(RCC_FLAG_PLLRDY) == RESET)
  // {
  // }

  // RCC_SYSCLKConfig(RCC_SYSCLKSource_PLLCLK);
  // while (RCC_GetSYSCLKSource() != 0x08)
  // {
  // }

  RCC_GetClocksFreq(&RCC_Clocks);

  RCC_APB1PeriphClockCmd(RCC_APB1Periph_USART2 |
      RCC_APB1Periph_USART3 |
                             RCC_APB1Periph_TIM2 |
                             RCC_APB1Periph_TIM3 |
                             RCC_APB1Periph_TIM4,
                         ENABLE);

  RCC_APB2PeriphClockCmd(RCC_APB2Periph_GPIOA |
                             RCC_APB2Periph_GPIOB |
                             RCC_APB2Periph_GPIOC |
                             RCC_APB2Periph_AFIO |
                             RCC_APB2Periph_ADC1,
                         ENABLE);
}

void LimitSwitch_Initialization(void)
{
  GPIO limitSwitch;
  limitSwitch.PortPin = LimitSwitch_PortPin;
  limitSwitch.Mode = GPIO_Mode_IPD;
  limitSwitch.Init();

  NVIC_InitTypeDef NVIC_InitStructure;
  NVIC_InitStructure.NVIC_IRQChannel = EXTI0_IRQn;
  NVIC_InitStructure.NVIC_IRQChannelPreemptionPriority = NVIC_PreemptionPriority_EXTI0;
  NVIC_InitStructure.NVIC_IRQChannelSubPriority = NVIC_SubPriority_EXTI0;
  NVIC_InitStructure.NVIC_IRQChannelCmd = ENABLE;
  NVIC_Init(&NVIC_InitStructure);

  GPIO_EXTILineConfig(GPIO_PortSourceGPIOA, GPIO_PinSource0);

  EXTI_InitTypeDef EXTI_InitStructure;
  EXTI_InitStructure.EXTI_Line = EXTI_Line0;
  EXTI_InitStructure.EXTI_Mode = EXTI_Mode_Interrupt;
  EXTI_InitStructure.EXTI_Trigger = EXTI_Trigger_Falling;
  EXTI_InitStructure.EXTI_LineCmd = ENABLE;
  EXTI_Init(&EXTI_InitStructure);
}
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

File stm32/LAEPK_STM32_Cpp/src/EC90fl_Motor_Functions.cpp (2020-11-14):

/**
 ******************************************************************************
 * @file    EC90fl_Motor_Functions.cpp
 * @author  ZiTe (honmonoh@gmail.com)
 * @version V1.0
 * @date    14-November-2020
 * @brief   Program body of MAXON EC90fl. BL-Motor.
 ******************************************************************************
 * @attention
 *
 * None
 *
 ******************************************************************************
 */

#include "EC90fl_Motor_Functions.hpp"

EC90Motor::EC90Motor(void)
{
  FunctionState.Mode = GPIO_Mode_Out_PP;
  FunctionState.Speed = GPIO_Speed_2MHz;

  Direction.Mode = GPIO_Mode_Out_PP;
  Direction.Speed = GPIO_Speed_2MHz;

  ReadyState.Mode = GPIO_Mode_IPD;

  RPM.Mode = GPIO_Mode_AIN;
}

void EC90Motor::Init(void)
{
  Speed.PortPin = PortPin_SpeedPWM;
  Speed.Timer = Timer_SpeedPWM;
  Speed.Channel = Channel_SpeedPWM;
  Speed.setFrequency(2000); // 2kHz.
  Speed.setDutyCycle(0);    // 0%.
  Speed.Init();
  Speed.Disable();

  FunctionState.PortPin = PortPin_FunctionState;
  FunctionState.Init();
  FunctionState.setValue(LOW); // Disable.

  Direction.PortPin = PortPin_Direction;
  Direction.Init();

  ReadyState.PortPin = PortPin_ReadyState;
  ReadyState.Init();

  RPM.PortPin = PortPin_RPM;
  RPM.Init();
}

void EC90Motor::Enable(void)
{
  Speed.Enable();
  FunctionState.setValue(HIGH);
}

void EC90Motor::Disable(void)
{
  FunctionState.setValue(LOW);
  Speed.Disable();
}

void EC90Motor::setDirection(EC90Motor::RotationDirectionTypeDef NewDirection)
{
  switch (NewDirection)
  {
  case CCW:
    Direction.setValue(HIGH); // HIGH: CCW
    break;
  case CW:
    Direction.setValue(LOW); // LOW: CW
    break;
  case ToggleDirection:
    Direction.toggleValue();
    break;
  }
}

void EC90Motor::setSpeed(uint16_t NewSpeed)
{
  Speed.setDutyCycle(NewSpeed);
}

EC90Motor::ReadyStateTypeDef EC90Motor::getReadyState(void)
{
  if (ReadyState.getValue() == HIGH)
    return Ready; // HIGH: Ready
  else
    return Fault; // LOW: Fault
}

EC90Motor::RotationDirectionTypeDef EC90Motor::getDirection(void)
{
  if (Direction.getValue() == HIGH)
    return CCW; // HIGH: CCW
  else
    return CW; // LOW: CW
}

uint16_t EC90Motor::getSpeed(void)
{
  return Speed.getDutyCycle();
}

/*********************************END OF FILE**********************************/

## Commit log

2019-10-23 Update code.add motorctrl-func
2019-10-25 增加MotorCtrl、SendStatus函數(未能動作)
2019-11-19 解決PWN與USARt衝突 換了部分腳位。USART現在可以正常運作，PWM還未測試。
2019-11-20 改函數名稱
2019-11-20 更新Pin_Mod() 註解
2019-11-21 修正PWM GPIO 設定
2019-11-21 改USART Motor-Ctrl指令
2019-12-11 PWM&USART完成
2019-12-12 加入USART之Toggle控制
2019-12-17 更新SendStatus功能
    加入讀取En/Disable;CCW/CW
2019-12-17 加入USART之reset功能
2019-12-19 加入馬達加速度控制
2019-12-19 改善馬達速度控制
    改成OD輸出、更新Delay
2019-12-25 修改註解、小幅度修USART內容
2019-12-25 將GPIO模式設定改成自己寫的函式
2019-12-25 修改註解
2019-12-25 改修SendSpeedValue()
2019-12-25 增加註解&修MotorAccelerationCtrl()
2020-03-25 新增“SG90_Testing_Model-01”資料夾
    ”SG90_Testing_Model-01“為測試SG90縮小模型之程式
2020-03-26 SG90可正常動作
2020-03-26 TesMod UART正常動作
    SG90-PWM無remap；USART OK
2020-03-26 TesMod ADC正常動作
2020-03-26 新增 ADC_Functions.c (未測試)
2020-04-08 加入轉速控制、電位器限位
2020-04-08 加入限動開關之外部中斷
2020-04-08 增加pot限位判斷
2020-04-08 POT限位可正常判斷
2020-04-08 POT限位修正（未完成）
2020-04-09 POT限位條件修正
    彎直極限可正常判斷
2020-04-09 增加POT限位極限flag清除
2020-04-09 極限停止關閉PWM輸出
2020-04-09 修正PWM起始值
2020-04-09 刪除限位開關外部中斷之防彈跳
2020-04-09 增加馬達控制限位事前判斷
2020-04-09 將ADC功能轉至專屬c檔
2020-04-09 修改ADC極限讀值
2020-07-02 增加c++檔案
2020-07-02 整合EPCUI
2020-07-02 add solidworks file
    [25 WG BEARING DS.sldprt, 3030鋁擠[01-v1.0].DXF, 3030鋁擠[01-v1.0].SLDPRT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]
2020-07-02 Add Inventor files
    [25 WG BEARING DS.ipt, EC90fl-160W-586655.ipt, SHD-25-2SH-CS.ipt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]
2020-07-02 Add model
    [3060鋁擠型(Prototype)-01_v1.DXF, 3060鋁擠型-小腿[01_v1.0].ipt]
2020-07-03 add 光遮斷器
    [光遮斷器[01-v1.0].SLDPRT]
2020-08-24 Create new stm32 project
2020-08-24 改成自己的函式庫
2020-08-29 將GPIO_init 函式改到main.cpp
2020-08-29 將NVIC_init函式移到mian.cpp
2020-08-29 刪除Full_init函式
2020-08-29 更新函式宣告
2020-08-29 將USART_init函式移到main.cpp
2020-08-29 將ADC_init函式移到main.cpp
2020-08-29 將PWM_init函式移到maio.cpp
2020-08-29 刪除ADC_init原本的原型宣告
2020-08-29 將RCC_init移到各功能init函式內
2020-08-29 刪除RCC_init函式
2020-08-31 將Class EC90 獨立檔案
2020-08-31 將joint相關函式獨立檔案
2020-08-31 更新ADC class
2020-08-31 將setValue改成switch
2020-08-31 加入標頭檔重複宣告預處理
2020-08-31 增加unit test程式
2020-08-31 增加User-button LED的單元測試
2020-08-31 增加USART senddata 的unit test
2020-08-31 增加ADCunit test
2020-08-31 更新ADC unit test
2020-09-01 更新PWM class
2020-09-01 增加PWN unit test
2020-09-01 更新EC90 class與增加其unit test
2020-09-01 更新joint calss與增加joint unit test
2020-09-01 將舊的、不需要的程式刪除
2020-09-01 刪除就Initfunctinos
2020-09-02 更新linclutde path
2020-09-02 增加Timer中斷unit test
2020-09-02 新增Timer_init function
2020-09-02 增加Board——init fuhctions
2020-09-02 Update Timer2 Period value 2000
2020-09-02 更新運動程式，以Timer中斷觸發
2020-09-02 發現等待ADC轉換完成判斷式無法跳出無限回圈 加上FIXME
2020-09-02 新增無Hallsensor之Joint class多型測試
2020-09-03 將Init改成#define巨集
2020-09-03 整合2條腿的init
2020-09-03 加入虛擬Hall sensor輸出程式
2020-09-03 修改PWM和Timer數值
2020-09-03 改腳位&USART傳送
2020-09-03 更新GPIO Mapping說明註解
2020-09-04 增加GPIO setValue多載
2020-09-04 將GPIO typedef加入強制轉型
2020-09-04 增加GPIO使用reg取得輸入
2020-09-04 增加GPIO建構子多載
2020-09-04 增加GPIO mapping port-B comments
2020-09-04 刪除衝突檔案
2020-09-04 增加緊急停止func
2020-09-04 增加Joint WHS class的stop函式多型
2020-09-04 增加Joint waitStop函式
2020-09-04 將第2條腿加上waitStop函式
2020-09-04 將MotionHandler由if-else改成switch
2020-09-04 刪除無用註解程式，將USART從joint改到main
2020-09-04 增加PC13 外部中斷以傳送資訊
2020-09-04 Add FIXME tag for UpdateInfo
    [main.cpp, main.hpp]
2020-09-06 將指標預設宣告為NULL
2020-09-06 刪除主無限迴圈內的按鈕偵測
2020-09-06 將#define init加上{}
2020-09-06 新增Joint SendInfo
2020-09-08 更改腳位
2020-09-08 更換腳位
2020-09-08 更改傳送訊息順序
2020-09-08 將極限開關的腳位換成#define
2020-09-08 改變初始化順序
2020-09-08 加入初期極限開關判斷
2020-09-09 加入EnableRight&Leftleg #define
2020-09-10 改ADC參數
2020-09-10 刪除joint等待停止判斷
2020-09-10 將joint動作整合進class
2020-09-10 將joint動作移到jointclass
2020-09-10 增加joint-mode 預處理器判斷
2020-09-10 更新joint-mode預處理器判斷和跟隨模式的MotionHandler
2020-09-10 修正JointWHS的程式
2020-09-10 更改預處理器判斷oint-mode
2020-09-10 Enable Right leg
2020-09-11 更新檔案
    [主電路板固定片[01_v1.0].SLDPRT, 定位多圈可變電阻固定片[02_v5.0].SLDPRT, 小腿固定片[01_v2.0].SLDPRT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]
2020-09-11 刪除JWHS 啟動的方向、PWM輸出
2020-09-11 刪除JWHS的PWM輸出
2020-09-12 更新RCC寫法
2020-09-12 更改Tim2的User-LED亮法
2020-09-12 改回Tim2 user-LEF亮發
2020-09-12 修正更新PWM頻率設定函式
2020-09-12 將Init-Func改回函式
2020-09-12 加入手動RCC時鐘設定並註解
2020-09-12 Update RCC FIXME tag comment
    [main.cpp]
2020-09-12 將虛擬Hall sensor改成用Timer數
2020-09-12 刪除無用的舊程式、Format
2020-09-12 修正左腿的運動訊息成L
2020-09-15 增加Joint getState 函式
2020-09-15 將Joint的enum加入代表數字
2020-09-15 註解掉Joint state 的 Direction
2020-09-15 加入基本控制項
2020-09-15 更新鮑率
2020-09-15 增加找不到serialPort的try
2020-09-15 將找不到SerialPort從try改成if-else
2020-09-15 加入SerialPort的接發程式
2020-09-15 改serialPort設定switch
2020-09-19 更新預處理器#define
2020-09-19 更新SerialPort讀取程式
2020-09-19 增加並修正SerialPort接收程式，並顯示在textBox
2020-09-19 將接收資料改爲以文字而非數字表示
2020-09-19 加入左腳資訊
2020-09-23 更新中斷優先級的寫法及數值
2020-09-23 更新修正藍牙接收
2020-09-25 增加無法自動傳送資訊的FIXME標籤
2020-10-26 換新馬達
2020-11-10 增加反轉AnglePOT設定
2020-11-10 增加 Enable AnglePOT #def
2020-11-10 將關節馬達速度改成用#define
2020-11-13 Move folder and files
    [25 WG BEARING DS.ipt, 25 WG BEARING DS.sldprt, 3030鋁擠[01-v1.0].DXF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]
2020-11-13 Add KiCad pcb files
    [LEAP.kicad_pcb, LEAP.sch]
2020-11-14 加入STOP、RESET及藍牙
2020-11-14 Update 3D model
    [25 WG BEARING DS.sldprt, 3030鋁擠型三角件M6[01-v1.0].SLDPRT, 3060鋁擠型-大腿[01_v1.0].SLDPRT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]
2020-11-14 增加各部分的說明MD
